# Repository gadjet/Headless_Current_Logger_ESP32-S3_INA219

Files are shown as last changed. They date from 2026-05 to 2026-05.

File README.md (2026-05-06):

# ESP32 Headless Solar Current Logger




A headless, web-configurable current logger designed to monitor solar panel charging in 12V vehicle systems. This device is designed to replace a standard fuse in a vehicle's fuse box, providing real-time and historical data on energy production and consumption.
It can also be used to monitor any low voltage DC current upto 3 Amps. 

| Top | Bottom | Real| Complete |
|---|---|---|---|
| 3D_PCB1_2026-05-03| 3D_PCB1a_2026-05-03|  | Complete |

## 🚀 Key Features

- **Headless Operation:** No physical buttons or screens. Full control via a mobile-friendly web dashboard.
- **WiFi Access Point:** Broadcasts its own network (**"SolarLogger"**) for easy connection in the field.
- **Advanced Web Dashboard:**
  - **Real-time Monitoring:** Live current (mA) and bus voltage (V) tracking.
  - **Integrated Session Stats:** Track Peak Charge, Peak Draw, and total Session Energy (mAh) at a glance.
  - **Live Bidirectional Chart:** Visualizes charging (Green) vs. discharging (Red) with dynamic Y-axis scaling.
  - **Historical Log Viewer:** View stored `.csv` files as interactive charts directly in the browser.
  - **Remote File Manager:** List, download, and delete log files over WiFi.
  - **Auto Time-Sync:** Automatically synchronizes with the connected smartphone's time and local timezone upon connection.
- **Configurable Logging:** Adjustable intervals (1s to 1min) and automatic file rotation.
- **CSV Data Logging:** Standard format compatible with Excel and data analysis tools.

## 🛠 Hardware Architecture

### Components
- **Microcontroller:** Seeed Studio Xiao ESP32 S3
- **Sensor:** INA219 (High-side current monitor, 100mΩ shunt)
- **Storage:** MicroSD Card Module (SPI interface)
- **Power:** Regulated vehicle power or USB-C (5V)

### Pin Mappings (Xiao ESP32 S3)
The firmware utilizes manual GPIO mapping to ensure consistent behavior across different board packages.

| Component | Pin Function | Xiao Pin | GPIO |
|---|---|---|---|
| **INA219**| SDA | D4 | 5 |
| | SCL | D5 | 6 |
| **SD Card**| CS | D3 | 4 |
| | MOSI | D10 | 9 |
| | MISO | D9 | 8 |
| | SCK | D8 | 7 |

## 💻 Software & Installation

### Prerequisites
- **Arduino IDE 2.x**
- **ESP32 Board Manager:** Espressif Systems (Select **Seeed Studio XIAO ESP32S3**)
- **Required Libraries:**
  - `Adafruit_INA219` (by Adafruit)
  - `SD`, `WiFi`, `WebServer`, `SPI`, `Wire` (Built-in ESP32 libraries)

### Configuration
Key flags at the top of the `.ino` sketch:
- `ENABLE_VOLTAGE`: Set to `true` to include bus voltage in logs and the web dashboard.
- `DEBUG_SERIAL`: Set to `true` to enable Serial monitoring at 115200 baud.

### Installation
1. Clone this repository.
2. Open `Headless_Solar_Logger/Headless_Solar_Logger.ino` in Arduino IDE.
3. Install the required libraries via the Library Manager.
4. Select **Seeed Studio XIAO ESP32S3** as your board.
5. Upload the sketch to your device.

## 📖 Usage Instructions

1. **Connect:** Power the device and connect your smartphone or laptop to the **"SolarLogger"** WiFi network (no password by default).
2. **Access Dashboard:** Open a web browser and navigate to `http://192.168.4.1`.
3. **Sync Time:** The device will automatically sync its internal clock with your browser's time on the first visit.
4. **Start Logging:** Select your desired interval and click **"START LOGGING"**.
5. **Monitor:** Use the live chart to watch solar performance. Green indicates the battery is being charged; Red indicates a draw.
6. **Data Retrieval:** Scroll to the "Stored Logs" section to view charts of previous sessions or download the `.csv` files for deep analysis.

##  Webpage Layout
WebPage (Medium)

## Parts assembly drawing with the 3D printed case
Assy_Drawing

## ⚖️ License
This project is licensed under the MIT License - see the [LICENSE](LICENSE) file for details (or just enjoy the code!).

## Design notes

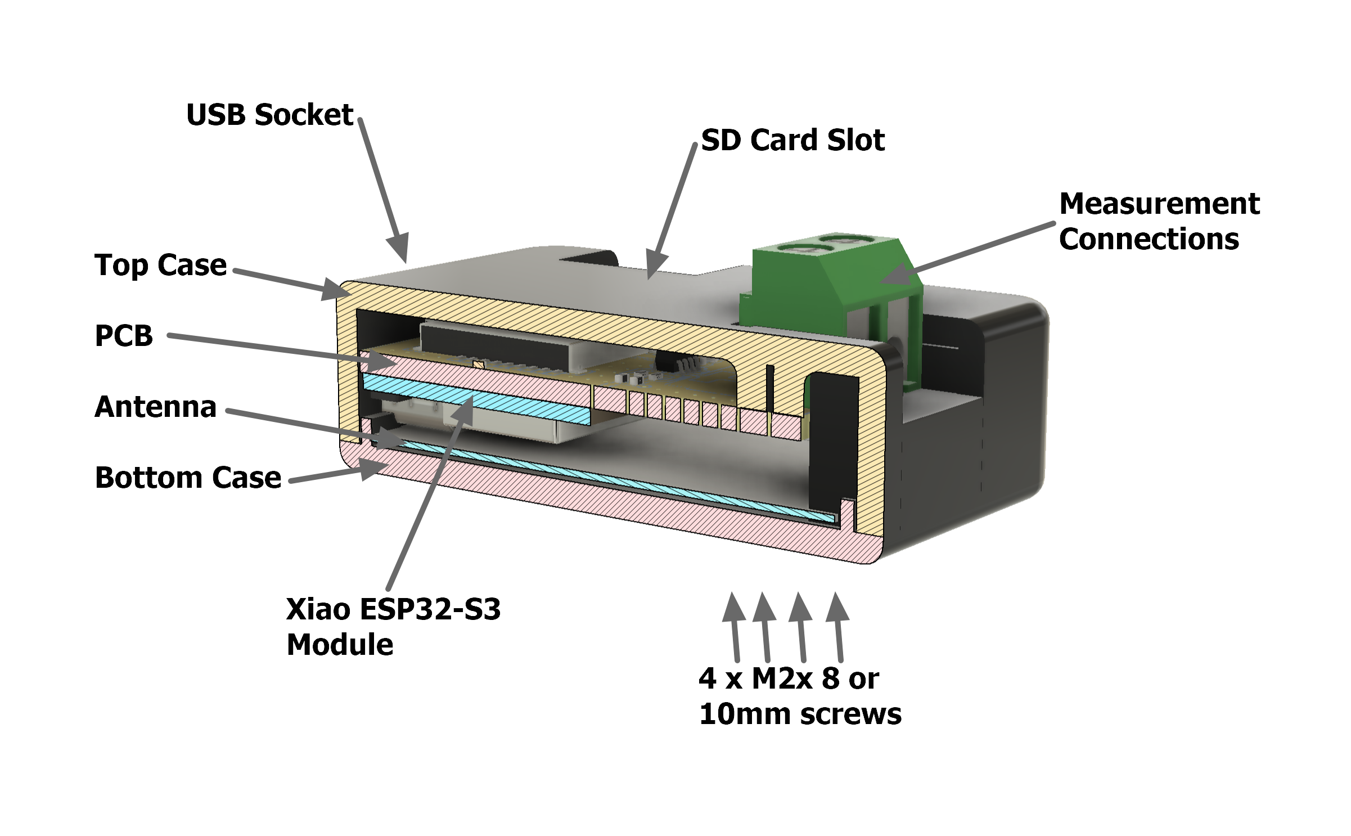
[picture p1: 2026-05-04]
Assy_Drawing.png

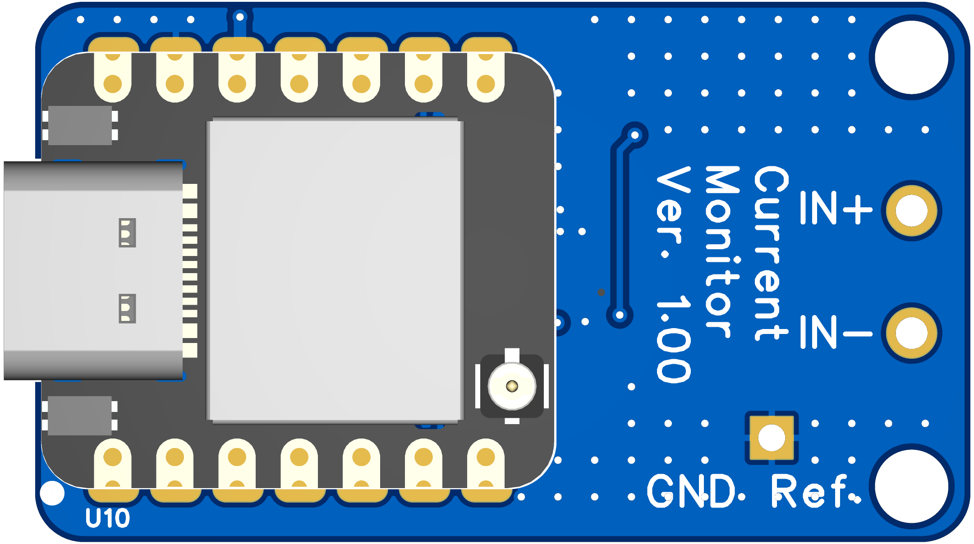
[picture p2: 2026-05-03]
images/3D_PCB1a_2026-05-03.png

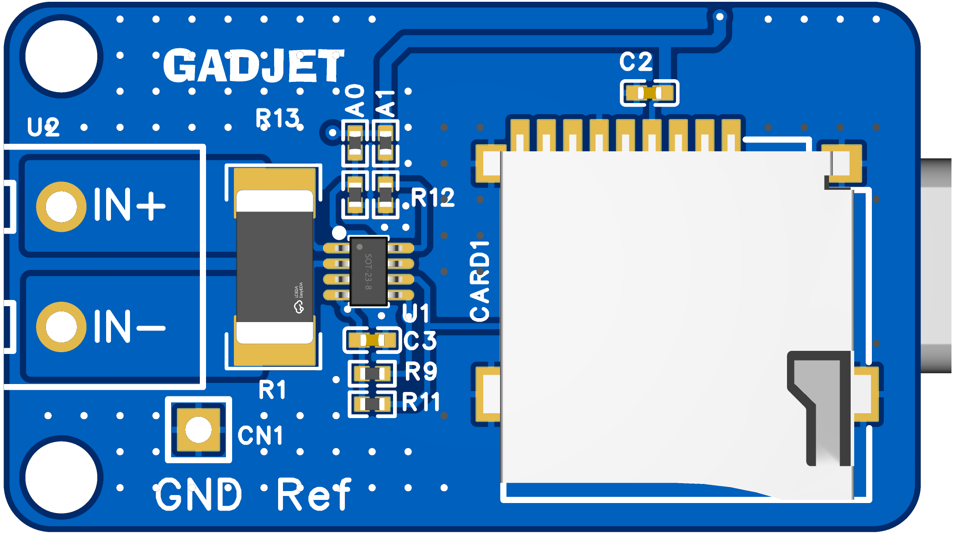
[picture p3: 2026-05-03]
images/3D_PCB1_2026-05-03.png

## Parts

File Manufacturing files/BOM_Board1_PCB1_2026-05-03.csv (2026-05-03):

No. | Quantity | Comment | Designator | Footprint | Value | Manufacturer Part | Manufacturer | Supplier Part | Supplier
1 | 2 | 100nF | C2,C3 | C0402 | 100nF | CL05B104KO5NNNC | SAMSUNG(三星) | C1525 | LCSC
2 | 1 | TF PUSH | CARD1 | TF-SMD_TF-PUSH |  | TF PUSH | SHOU HAN(首韩) | C393941 | LCSC
3 | 1 | 100mΩ | R1 | RES-SMD_L6.4-W3.2-R2512 | 100mΩ | FPM253WFR100TM | FOJAN(富捷) | C7419997 | LCSC
4 | 2 | 4.7kΩ | R9,R11 | R0402 | 4.7kΩ | 0402WGF4701TCE | UNI-ROYAL(厚声) | C25900 | LCSC
5 | 2 | 10kΩ | R12,R13 | R0402 | 10kΩ | 0402WGF1002TCE | UNI-ROYAL(厚声) | C25744 | LCSC
6 | 1 | INA219AIDCNT | U1 | SOT-23-8_L2.9-W1.6-P0.65-LS2.8-BR |  | INA219AIDCNT | TI(德州仪器) | C2865405 | LCSC

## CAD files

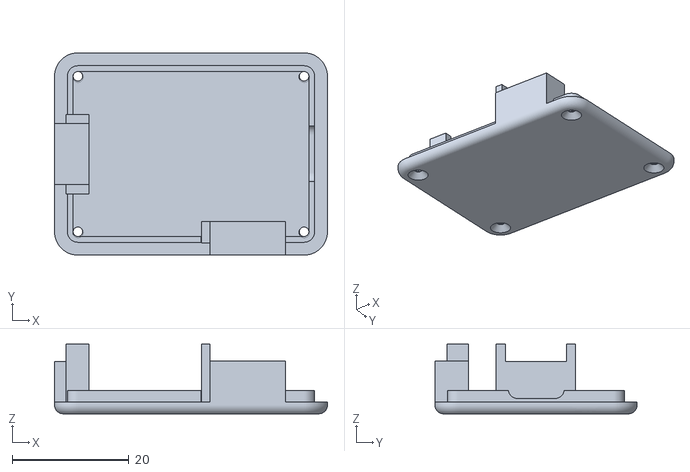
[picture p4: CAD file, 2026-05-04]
3D Case STLs/Case_Bottom.stl
46.7 x 34.6 x 11.9

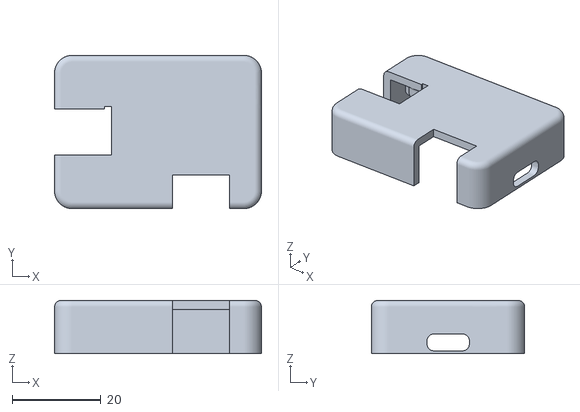
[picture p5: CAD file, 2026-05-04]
3D Case STLs/Case_Top.stl
46.7 x 34.6 x 12.0

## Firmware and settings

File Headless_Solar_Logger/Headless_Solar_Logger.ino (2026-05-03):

#include <WiFi.h>
#include <WebServer.h>
#include <Wire.h>
#include <SPI.h>
#include <SD.h>
#include <Adafruit_INA219.h>
#include <time.h>

/* ==========================================
 * 1. CONFIGURATION & PINS (Xiao ESP32 S3)
 * ========================================== */
#define ENABLE_VOLTAGE false  // Set to true to log and display Bus Voltage
#define DEBUG_SERIAL true     // Set to true to enable Serial debugging

// Manually define XIAO pins if not defined by the board package
#ifndef D3
  #define D3 4
  #define D4 5
  #define D5 6
  #define D8 7
  #define D9 8
  #define D10 9
#endif

// I2C Pins for INA219
#define I2C_SDA D4
#define I2C_SCL D5

// SPI Pins for SD Card
#define SD_MOSI D10
#define SD_MISO D9
#define SD_SCK  D8
#define SD_CS   D3

const char* ssid = "SolarLogger";
const char* password = NULL; // Open network

/* --- 2. OBJECTS & GLOBALS --- */
Adafruit_INA219 ina219;
WebServer server(80);

// State & Config
uint32_t log_interval_ms = 10000;
bool isLogging = false;
bool sdAvailable = false;
bool ina219Available = false;
bool timeIsSet = false;

// Time Tracking
time_t base_epoch = 0;
uint32_t base_millis = 0;
int tz_offset_sec = 0;

// Logging State
uint32_t recordsInFile = 0;
String currentLogFileName = "";
const uint32_t MAX_RECORDS = 5000;

/* --- 3. WEB INTERFACE (HTML/JS) --- */
const char INDEX_HTML[] PROGMEM = R"=====(
<!DOCTYPE html>
<html>
<head>
    <meta name="viewport" content="width=device-width, initial-scale=1">
    <title>Solar Logger</title>
    <style>
        :root {
            --bg: #0f172a;
            --card-bg: #1e293b;
            --text: #f8fafc;
            --text-dim: #94a3b8;
            --green: #22c55e;
            --red: #ef4444;
            --blue: #3b82f6;
            --border: #334155;
        }
        body { font-family: 'Segoe UI', system-ui, -apple-system, sans-serif; background: var(--bg); color: var(--text); margin: 0; padding: 20px; display: flex; flex-direction: column; align-items: center; }
        .card { background: var(--card-bg); padding: 24px; border-radius: 16px; width: 100%; max-width: 400px; box-shadow: 0 10px 25px -5px rgba(0,0,0,0.3); border: 1px solid var(--border); }
        h2 { margin: 0 0 20px 0; font-weight: 600; font-size: 1.25rem; color: var(--text-dim); }
        .val-container { margin: 20px 0; display: flex; justify-content: space-between; align-items: center; }
        .val-main { text-align: left; }
        .val { font-size: 4rem; font-weight: 700; line-height: 1; margin-bottom: 4px; transition: color 0.3s; }
        .unit { font-size: 1rem; color: var(--text-dim); text-transform: uppercase; letter-spacing: 0.1em; }
        #voltage_val { font-size: 1.25rem; color: var(--blue); margin-top: 8px; font-weight: 500; }
        
        .side-stats { display: flex; flex-direction: column; gap: 12px; text-align: right; border-left: 1px solid var(--border); padding-left: 15px; }
        .side-stat { display: flex; flex-direction: column; }
        .side-label { font-size: 0.65rem; color: var(--text-dim); text-transform: uppercase; font-weight: 600; }
        .side-value { font-size: 0.9rem; font-weight: 700; }

        #chart-container { width: 100%; height: 160px; margin: 20px 0; background: rgba(0,0,0,0.2); border-radius: 8px; overflow: hidden; position: relative; }
        canvas { width: 100%; height: 100%; }

        #status-bar { display: flex; gap: 8px; margin-bottom: 24px; width: 100%; max-width: 400px; }
        .indicator { flex: 1; padding: 6px; border-radius: 20px; background: var(--border); color: var(--text-dim); font-size: 0.7rem; font-weight: 700; text-align: center; transition: all 0.4s; border: 1px solid transparent; }
        .indicator.ok { background: rgba(34, 197, 94, 0.1); color: var(--green); border-color: rgba(34, 197, 94, 0.2); }
        .indicator.fail { background: rgba(239, 68, 68, 0.1); color: var(--red); border-color: rgba(239, 68, 68, 0.2); }

        .control-group { background: rgba(255,255,255,0.03); padding: 16px; border-radius: 12px; margin-bottom: 16px; text-align: left; }
        label { display: block; font-size: 0.8rem; color: var(--text-dim); margin-bottom: 8px; }
        select { width: 100%; padding: 10px; border-radius: 8px; background: var(--bg); color: var(--text); border: 1px solid var(--border); font-size: 1rem; }
        
        button { width: 100%; padding: 14px; font-size: 1rem; font-weight: 600; border: none; border-radius: 12px; cursor: pointer; transition: all 0.2s; margin-top: 8px; }
        .btn-start { background: var(--green); color: white; }
        .btn-start:hover { filter: brightness(1.1); }
        .btn-stop { background: var(--red); color: white; }
        .btn-stop:hover { filter: brightness(1.1); }

        .log-list { margin-top: 32px; width: 100%; max-width: 400px; text-align: left; }
        .log-header { font-size: 0.9rem; font-weight: 600; color: var(--text-dim); margin-bottom: 12px; display: flex; justify-content: space-between; }
        .log-item { background: var(--card-bg); padding: 12px 16px; border-radius: 12px; margin-bottom: 8px; border: 1px solid var(--border); display: flex; justify-content: space-between; align-items: center; animation: slideIn 0.3s ease-out; }
        .log-info { display: flex; flex-direction: column; }
        .log-name { font-size: 0.9rem; font-weight: 500; }
        .log-size { font-size: 0.75rem; color: var(--text-dim); }
        .log-actions { display: flex; gap: 16px; align-items: center; }
        .log-actions svg { width: 20px; height: 20px; cursor: pointer; fill: var(--text-dim); transition: fill 0.2s; }
        .log-actions .btn-download:hover svg { fill: var(--blue); }
        .log-actions .btn-view:hover svg { fill: var(--green); }
        .log-actions .btn-del:hover svg { fill: var(--red); }

        /* Log Viewer Modal */
        #viewer-modal { display: none; position: fixed; inset: 0; background: var(--bg); z-index: 2000; flex-direction: column; padding: 20px; overflow-y: auto; }
        .viewer-header { display: flex; justify-content: space-between; align-items: center; margin-bottom: 20px; width: 100%; max-width: 800px; margin-inline: auto; }
        .viewer-title { font-weight: 600; color: var(--text-dim); }
        .btn-close { padding: 8px 16px; background: var(--border); border-radius: 8px; cursor: pointer; font-size: 0.9rem; color: var(--text); }
        #viewer-chart-container { width: 100%; max-width: 800px; height: 300px; background: rgba(0,0,0,0.2); border-radius: 12px; margin: 0 auto 20px auto; position: relative; }
        .viewer-stats { display: grid; grid-template-columns: repeat(auto-fit, minmax(150px, 1fr)); gap: 12px; width: 100%; max-width: 800px; margin-inline: auto; }

        /* Toast Notifications */
        #toast-container { position: fixed; top: 20px; right: 20px; left: 20px; display: flex; flex-direction: column; align-items: center; pointer-events: none; z-index: 1000; }
        .toast { background: var(--card-bg); color: var(--text); padding: 12px 24px; border-radius: 12px; box-shadow: 0 10px 15px -3px rgba(0,0,0,0.4); border: 1px solid var(--border); margin-bottom: 10px; animation: toastIn 0.3s ease-out, toastOut 0.3s ease-in 2.7s forwards; font-size: 0.9rem; pointer-events: auto; }
        
        @keyframes slideIn { from { opacity: 0; transform: translateY(10px); } to { opacity: 1; transform: translateY(0); } }
        @keyframes toastIn { from { opacity: 0; transform: translateY(-20px); } to { opacity: 1; transform: translateY(0); } }
        @keyframes toastOut { to { opacity: 0; transform: translateY(-20px); } }
    </style>
</head>
<body>
    <div id="toast-container"></div>
    
    <div id="viewer-modal">
        <div class="viewer-header">
            <div class="viewer-title" id="viewer-filename">Log View</div>
            <div class="btn-close" onclick="closeViewer()">Close</div>
        </div>
        <div id="viewer-chart-container">
            <canvas id="viewerChart"></canvas>
        </div>
        <div class="viewer-stats" id="viewer-stats"></div>
    </div>

    <div id="status-bar">
        <div id="stat-sensor" class="indicator">SENSOR</div>
        <div id="stat-sd" class="indicator">SD CARD</div>
        <div id="stat-log" class="indicator">LOGGING</div>
    </div>

    <div class="card">
        <h2>Live Monitoring</h2>
        <div class="val-container">
            <div class="val-main">
                <div id="current_val" class="val">0</div>
                <div class="unit">mA Current</div>
                <div id="voltage_val">0.00 V</div>
            </div>
            <div class="side-stats">
                <div class="side-stat">
                    <span class="side-label">Peak Charge</span>
                    <span id="peak-charge" class="side-value" style="color:var(--green)">0 mA</span>
                </div>
                <div class="side-stat">
                    <span class="side-label">Peak Draw</span>
                    <span id="peak-draw" class="side-value" style="color:var(--red)">0 mA</span>
                </div>
                <div class="side-stat">
                    <span class="side-label">Energy</span>
                    <span id="session-ah" class="side-value" style="color:var(--blue)">0 mAh</span>
                </div>
            </div>
        </div>

        <div id="chart-container">
            <canvas id="liveChart"></canvas>
        </div>

        <div class="control-group">
            <label>Logging Interval</label>
            <select id="interval" onchange="updateConfig()">
                <option value="1000">Every 1 Second</option>
                <option value="5000">Every 5 Seconds</option>
                <option value="10000" selected>Every 10 Seconds</option>
                <option value="30000">Every 30 Seconds</option>
                <option value="60000">Every 1 Minute</option>
            </select>
        </div>

        <button id="logBtn" class="btn-start" onclick="toggleLogging()">START LOGGING</button>
    </div>

    <div class="log-list" id="log-list">
        <!-- Files populated here -->
    </div>

    <script>
        let dataHistory = [];
        const maxPoints = 60;
        let peakCharge = 0;
        let peakDraw = 0;
        let total_mAh = 0;
        let lastUpdateTime = Date.now();

        function showToast(msg) {
            const container = document.getElementById('toast-container');
            const toast = document.createElement('div');
            toast.className = 'toast';
            toast.innerText = msg;
            container.appendChild(toast);
            setTimeout(() => toast.remove(), 3000);
        }

        function syncTime() {
            const now = Math.floor(Date.now() / 1000);
            const tz = -new Date().getTimezoneOffset() * 60;
            fetch(`/sync?t=${now}&tz=${tz}`).then(() => {
                showToast("Time Synchronized");
                refreshLogs();
            });
        }

        function drawChart() {
            const canvas = document.getElementById('liveChart');
            const ctx = canvas.getContext('2d');
            const w = canvas.width = canvas.offsetWidth * window.devicePixelRatio;
            const h = canvas.height = canvas.offsetHeight * window.devicePixelRatio;
            ctx.scale(window.devicePixelRatio, window.devicePixelRatio);
            const sw = canvas.offsetWidth;
            const sh = canvas.offsetHeight;
            const chartLeft = 55;

            ctx.clearRect(0, 0, sw, sh);
            
            let maxAbs = Math.max(...dataHistory.map(Math.abs), 100) * 1.2;
            
            // Grid & Labels
            const niceSteps = [10, 20, 50, 100, 200, 500, 1000, 2000, 5000];
            let step = niceSteps.find(s => (maxAbs / s) <= 8) || 1000;
            
            ctx.font = '10px sans-serif';
            ctx.textAlign = 'right';
            ctx.fillStyle = 'rgba(255,255,255,0.3)';
            ctx.strokeStyle = 'rgba(255,255,255,0.05)';
            ctx.lineWidth = 1;

            for (let v = -Math.floor(maxAbs/step)*step; v <= maxAbs; v += step) {
                let y = (sh / 2) - (v / maxAbs) * (sh / 2);
                if (y < 10 || y > sh - 10) continue;
                ctx.beginPath(); ctx.moveTo(chartLeft, y); ctx.lineTo(sw, y); ctx.stroke();
                ctx.fillText((v > 0 ? '+' : '') + v, chartLeft - 5, y + 3);
            }

            // Zero Line
            ctx.strokeStyle = 'rgba(255,255,255,0.2)';
            ctx.setLineDash([5, 5]);
            ctx.beginPath();
            ctx.moveTo(chartLeft, sh/2);
            ctx.lineTo(sw, sh/2);
            ctx.stroke();
            ctx.setLineDash([]);

            if (dataHistory.length < 2) return;

            // Draw Gradient Area
            const grad = ctx.createLinearGradient(0, 0, 0, sh);
            grad.addColorStop(0, 'rgba(34, 197, 94, 0.2)');
            grad.addColorStop(0.5, 'rgba(34, 197, 94, 0)');
            grad.addColorStop(0.5, 'rgba(239, 68, 68, 0)');
            grad.addColorStop(1, 'rgba(239, 68, 68, 0.2)');

            ctx.fillStyle = grad;
            ctx.beginPath();
            ctx.moveTo(chartLeft, sh/2);
            dataHistory.forEach((v, i) => {
                const x = chartLeft + (i / (maxPoints - 1)) * (sw - chartLeft);
                const y = (sh / 2) - (v / maxAbs) * (sh / 2);
                ctx.lineTo(x, y);
            });
            ctx.lineTo(sw, sh/2);
            ctx.closePath();
            ctx.fill();

            // Draw Line
            ctx.beginPath();
            ctx.lineWidth = 2;
            dataHistory.forEach((v, i) => {
                const x = chartLeft + (i / (maxPoints - 1)) * (sw - chartLeft);
                const y = (sh / 2) - (v / maxAbs) * (sh / 2);
                if (i === 0) ctx.moveTo(x, y); else ctx.lineTo(x, y);
            });
            ctx.strokeStyle = '#3b82f6';
            ctx.stroke();
        }

        function updateData() {
            fetch('/status').then(r => r.json()).then(data => {
                if (data.current !== undefined) {
                    const current = Math.round(data.current);
                    document.getElementById('current_val').innerText = current;
                    document.getElementById('current_val').style.color = current >= 0 ? 'var(--green)' : 'var(--red)';
                    
                    // Stats
                    if (current > peakCharge) peakCharge = current;
                    if (current < peakDraw) peakDraw = current;
                    
                    const now = Date.now();
                    const dt = (now - lastUpdateTime) / 1000 / 3600; // hours
                    total_mAh += Math.abs(current) * dt;
                    lastUpdateTime = now;

                    document.getElementById('peak-charge').innerText = peakCharge + " mA";
                    document.getElementById('peak-draw').innerText = peakDraw + " mA";
                    document.getElementById('session-ah').innerText = Math.round(total_mAh) + " mAh";

                    dataHistory.push(current);
                    if (dataHistory.length > maxPoints) dataHistory.shift();
                    drawChart();
                }
                
                document.getElementById('stat-sensor').className = data.ina ? "indicator ok" : "indicator fail";
                document.getElementById('stat-sd').className = data.sd ? "indicator ok" : "indicator fail";
                document.getElementById('stat-log').className = data.logging ? "indicator ok" : "indicator";

                if (data.voltage !== null) {
                    document.getElementById('voltage_val').innerText = data.voltage.toFixed(2) + " V";
                    document.getElementById('voltage_val').style.display = "block";
                }

                const btn = document.getElementById('logBtn');
                if (data.logging) {
                    btn.innerText = "STOP LOGGING (" + data.records + ")";
                    btn.className = "btn-stop";
                } else {
                    btn.innerText = "START LOGGING";
                    btn.className = "btn-start";
                }
            }).catch(() => {});
        }

        function refreshLogs() {
            fetch('/list').then(r => r.json()).then(files => {
                files.sort((a, b) => b.name.localeCompare(a.name));
                const list = document.getElementById('log-list');
                list.innerHTML = '<div class="log-header"><span>Stored Logs</span><span>' + files.length + ' files</span></div>';
                files.forEach(f => {
                    const item = document.createElement('div');
                    item.className = 'log-item';
                    item.innerHTML = `
                        <div class="log-info">
                            <span class="log-name">${f.name}</span>
                            <span class="log-size">${(f.size/1024).toFixed(1)} KB</span>
                        </div>
                        <div class="log-actions">
                            <div class="btn-view" onclick="viewLog('${f.name}')" title="View Chart">
                                <svg viewBox="0 0 24 24"><path d="M12 4.5C7 4.5 2.73 7.61 1 12c1.73 4.39 6 7.5 11 7.5s9.27-3.11 11-7.5c-1.73-4.39-6-7.5-11-7.5zM12 17c-2.76 0-5-2.24-5-5s2.24-5 5-5 5 2.24 5 5-2.24 5-5 5zm0-8c-1.66 0-3 1.34-3 3s1.34 3 3 3 3-1.34 3-3-1.34-3-3-3z"/></svg>
                            </div>
                            <a href="/download?file=${f.name}" class="btn-download" title="Download CSV">
                                <svg viewBox="0 0 24 24"><path d="M19 9h-4V3H9v6H5l7 7 7-7zM5 18v2h14v-2H5z"/></svg>
                            </a>
                            <div class="btn-del" onclick="deleteFile('${f.name}')" title="Delete File">
                                <svg viewBox="0 0 24 24"><path d="M6 19c0 1.1.9 2 2 2h8c1.1 0 2-.9 2-2V7H6v12zM19 4h-3.5l-1-1h-5l-1 1H5v2h14V4z"/></svg>
                            </div>
                        </div>
                    `;
                    list.appendChild(item);
                });
            });
        }

        function viewLog(name) {
            document.getElementById('viewer-filename').innerText = name;
            document.getElementById('viewer-modal').style.display = 'flex';
            document.getElementById('viewer-stats').innerHTML = "Loading data...";
            
            fetch(`/download?file=${name}`).then(r => r.text()).then(csv => {
                const lines = csv.split('\n').filter(l => l.trim() && !l.startsWith('Timestamp'));
                const values = lines.map(l => parseFloat(l.split(',').pop()));
                
                if (values.length === 0) {
                    document.getElementById('viewer-stats').innerHTML = "No data in file";
                    return;
                }

                const max = Math.max(...values);
                const min = Math.min(...values);
                const avg = values.reduce((a, b) => a + b, 0) / values.length;

                document.getElementById('viewer-stats').innerHTML = `
                    <div class="stat-card"><div class="stat-label">Max Current</div><div class="stat-value" style="color:var(--green)">${max.toFixed(0)} mA</div></div>
                    <div class="stat-card"><div class="stat-label">Min Current</div><div class="stat-value" style="color:var(--red)">${min.toFixed(0)} mA</div></div>
                    <div class="stat-card"><div class="stat-label">Average</div><div class="stat-value" style="color:var(--blue)">${avg.toFixed(0)} mA</div></div>
                    <div class="stat-card"><div class="stat-label">Samples</div><div class="stat-value">${values.length}</div></div>
                `;

                const canvas = document.getElementById('viewerChart');
                const ctx = canvas.getContext('2d');
                const sw = canvas.width = canvas.offsetWidth * window.devicePixelRatio;
                const sh = canvas.height = canvas.offsetHeight * window.devicePixelRatio;
                ctx.scale(window.devicePixelRatio, window.devicePixelRatio);
                const w = canvas.offsetWidth;
                const h = canvas.offsetHeight;
                const chartLeft = 55;

                ctx.clearRect(0, 0, w, h);
                let maxAbs = Math.max(Math.abs(max), Math.abs(min), 100) * 1.2;

                // Grid & Labels
                const niceSteps = [10, 20, 50, 100, 200, 500, 1000, 2000, 5000];
                let step = niceSteps.find(s => (maxAbs / s) <= 8) || 1000;
                
                ctx.font = '10px sans-serif';
                ctx.textAlign = 'right';
                ctx.fillStyle = 'rgba(255,255,255,0.3)';
                ctx.strokeStyle = 'rgba(255,255,255,0.05)';
                ctx.lineWidth = 1;

                for (let v = -Math.floor(maxAbs/step)*step; v <= maxAbs; v += step) {
                    let y = (h / 2) - (v / maxAbs) * (h / 2);
                    if (y < 10 || y > h - 10) continue;
                    ctx.beginPath(); ctx.moveTo(chartLeft, y); ctx.lineTo(w, y); ctx.stroke();
                    ctx.fillText((v > 0 ? '+' : '') + v, chartLeft - 5, y + 3);
                }

                // Zero Line
                ctx.strokeStyle = 'rgba(255,255,255,0.2)';
                ctx.setLineDash([5, 5]);
                ctx.beginPath(); ctx.moveTo(chartLeft, h/2); ctx.lineTo(w, h/2); ctx.stroke();
                ctx.setLineDash([]);
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
void loop() {
    server.handleClient();

    static uint32_t last_log = 0;
    if (isLogging && (millis() - last_log >= log_interval_ms)) {
        last_log = millis();
        float current = ina219.getCurrent_mA();
        float voltage = ina219.getBusVoltage_V() + (ina219.getShuntVoltage_mV() / 1000.0);
        logToSD(current, voltage);
    }
    
    delay(10);
}

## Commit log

2026-05-03 Update README to include current monitoring capability
    Added capability to monitor low voltage DC current up to 3 Amps.
2026-05-04 Add files via upload
    3D case STL files added
    [Case_Bottom.stl, Case_Top.stl]
2026-05-04 Add files via upload
    Assembly drawing

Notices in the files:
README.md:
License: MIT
